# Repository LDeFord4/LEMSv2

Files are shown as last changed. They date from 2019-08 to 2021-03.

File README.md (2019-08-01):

# LEMSv2
This is the repository for the second version of the LEMS Sensor Stations. Stay tuned, information will be added as it is generated. A majority of the documentation will be added to this file.

Note that a peer-reviewed description of LEMSv1 may be found here: https://iopscience.iop.org/article/10.1088/1361-6501/aa97fb

### General TODO

1. Check validity of filenames with more than 8 characters
2. Decagon, the manufacturer of the 5TM soil sensors, has changed their name to Meter, and the 5TM is now called the ECH20 5TM. The DS2 is now called the Atmos 22. The documentation will need to be changed and will probably be done slowly.
3. Major Change: Change the code to read parameters from a text file on the SD card. See if possible to read code from SD card.
4. Delete or separate "File List" from README? Makes it clunky, hard to keep updated. Goal is for files to self explanatory 
5. Update DS2 code to use EnviroDIY's SDI12 library instead of custom library

### PCB TODO
1. Change the parts in the eagle files for BOM lines 11, 29, 30. These parts were out of stock and were replaced by different parts during manufacturing.

### File List
* Code/
  * `Code Instructions.md` - Instructions for uploading
  * LEMSv2/
    * `LEMSv2.ino` - LEMS Arduino Code
    * `DS3231_Alarm1.h` - Header file for corresponding `.cpp` file
    * `DS3231_Alarm1.cpp` - File used to set DS3231 Alarm 1. Developed in test code then copied to this folder
    * `d5TM.h` - Header file for corresponding `.cpp` file
    * `d5TM.cpp` - Library used to interact with 5TM. Developed in test code then copied to this folder
  * Test Code/
    * ADS1115_Test/
      * `ADS1115_Test.ino` - Test code for ADS1115 ADC
    * DS3231_Test/
      * `DS3231_Test.ino` - Test code for DS3231 RTC. Test DS3231 alarm 1
      * `DS3231_Alarm1.h` - Header file for corresponding `.cpp` file
      * `DS3231_Alarm1.c` - Library used to set DS3231 Alarm 1. Developed in here then copied to main code folder
    * DS2_Test/
      * `DS2_Test.ino` - Test code for DS2 anemometer
      * `DS2.h` - Header file for corresponding `.cpp` file
      * `DS2.cpp` - Library used to interact with DS2. Developed here then copied to main code folder
      * `LICENSE` - License to be included with the `SDI12_Zero` library
      * `LICENSE-examples.md` - License to be included with the `SDI12_Zero` library
      * `SDI12_Zero.h` - Header file for corresponding `.cpp` file
      * `SDI12_Zero.cpp` - Library used by DS2 library to interact with DS2. Implements the SDI12 protocal for Arduino Zero.
    * Li200_Test/
      * `Li200_Test.ino` - Test Li200 with intermediate values in calculations printed
    * Teros21_Test/
      * `Teros21_Test.ino` - Test Teros21 and library.
    * Test_5TM/
      * `Test_5TM.ino` - Test code for 5TM Library. 5TM has been working since LEMSv1 but is now made into a library.
      * `d5TM.h` - Header file for corresponding `.cpp` file
      * `d5TM.cpp` - Library used to interact with 5TM. Developed here then copied to main code folder
  * Time_Set/
    * `Time_Set.ino` - Code used to set the time on the DS3231 real time clock
* Data Manipulation/
  * `LemsPlot.m` - View LEMSv2 data plots. Not perfectly adaptable to any file, but will work for a fully instrumented station. To work properly, requires the [Intelligent Dynamic Date Ticks](https://www.mathworks.com/matlabcentral/fileexchange/27075-intelligent-dynamic-date-ticks) file from MathWorks. Can work without it though by commenting out the lines that use it.
  * `importfile.m` - Used to import the LEMSv2 data files. Can only be used on data files from fully instrumented LEMS.
* Hardware Information/
  * `Bill of Materials.xlsx` - Complete parts list
  * `Calibration Constants.xlsx` - Calibration constants for various instruments. For now, only contains Li200 constants.
  * Data Sheets/
    * Multiple data sheets for components
  * Li200R Base/
    * Solidworks/
      * Contains Solidworks files for Li200R base
    * STL Files/
      * Contains print ready STL files for Li200R base
    * `Build Instructions.md` - Tools required for making the Li200R base
  * MLX Housing/
    * `MLX Housing Build Instructions` - Build instructions for MLX90615 housing
  * PCB/
    * `LEMSv2 Board.pdf` - PDF of PCB for easy reference
    * `LEMSv2 Schematic.pdf` - PDF of schematic for easy reference
    * `SAMD21 Breakout Board.jpg` - Reference picture for microcontroller board
  * `Pin List.xlsx` - Pin connection list for SAMD21 Dev Breakout Board
  * `Possible Parts.txt` - Potential parts/Manufacturers to add/use in the future
  * Transimpedance Amplifier/
    * `Transimpedance_Amplifier_Calculations.ipynb` - Jupyter notebook containing transimpedance amplifier calculations
  * `Wiring Information.xlsx` - Information about wiring. What connects to what, etc. Work in progress.
* `LICENSE.TXT` - License
* PCB/
  * LEMSv2 PCB/
    * `Centroid_ScreamingCircuits_smd.ulp` - Eagle ULP script to create centroid data for screaming circuits
    * Gerbers/
      * Contains gerbers for board, plus the panelized gerbers supplied by OSH Park. Also contains the centroid file for Screaming Circuits.
    * `LEMSv2.sch` - LEMSv2 shield schematic
    * `LEMSv2.brd` - LEMSv2 shield layout
    * `OSH_DesignRules.dru` - Eagle design rules for OSH Park
    * `OSHPark_2layer_Eagle7.2.cam` - Modified cam job for OSH Park
  * LEMSv2 PCB Library/
    * `LEMSv2.lbr` - Parts used in the LEMSv2 shield
* `Possible Problems.md` - List of potential hardware problems in the LEMS. Prefer to not have duplicate entries, i.e. one line per problem.
* `README.md` - If you read this line you're actually reading the README. Good job!

### Dependencies
Only 3rd party software dependencies are included in this list. Libraries built into the Arduino software or created for the LEMSv2 software isn't included. You will need the most recent version of the [Arduino IDE](https://www.arduino.cc/en/Main/Software) installed.

* [Adafruit RTC Library](https://github.com/adafruit/RTClib)
* [Adafruit SHT31 Library](https://github.com/adafruit/Adafruit_SHT31)
* [Adafruit Sensor Library](https://github.com/adafruit/Adafruit_Sensor)
* [Adafruit BMP280 Library](https://github.com/adafruit/Adafruit_BMP280_Library)
* [Adafruit MLX90614 Library](https://github.com/adafruit/Adafruit-MLX90614-Library)
* [EnviroDIY SDI-12 Library](https://github.com/EnviroDIY/Arduino-SDI-12) 
* [Soligen2010's fork of the Adafruit ADS1x15 Library](https://github.com/soligen2010/Adafruit_ADS1X15). The default Adafruit ADS1x15 library **doesn't** work.
* In addition, the Sparkfun SAMD21 [board definition](https://raw.githubusercontent.com/sparkfun/Arduino_Boards/master/IDE_Board_Manager/package_sparkfun_index.json
  ) needs to be installed into the Arduino IDE. See [here](https://learn.sparkfun.com/tutorials/samd21-minidev-breakout-hookup-guide/setting-up-arduino) for more info.

### Miscellaneous Notes

- ADS1115 single ended resolution calculation information can be found [here](https://e2e.ti.com/support/data_converters/precision_data_converters/f/73/t/489070)
- ADS1115 over range input information can be found [here](https://e2e.ti.com/support/data_converters/precision_data_converters/f/73/p/398187/1407689#1407689) and [here](https://e2e.ti.com/support/data_converters/precision_data_converters/f/73/t/378122)

### Acknowledgements

* Thanks to [Sparkfun](https://www.sparkfun.com) and [Adafruit](https://www.adafruit.com) for Arduino libraries, components, tutorials, and eagle parts. Many designs and eagle components are directly used from them. Also thanks to [OSH Park](www.oshpark.com) and [Screaming Circuits](www.screamingcircuits.com) for the excellent PCBs and assembly. They were instrumental in getting LEMSv2 completed.

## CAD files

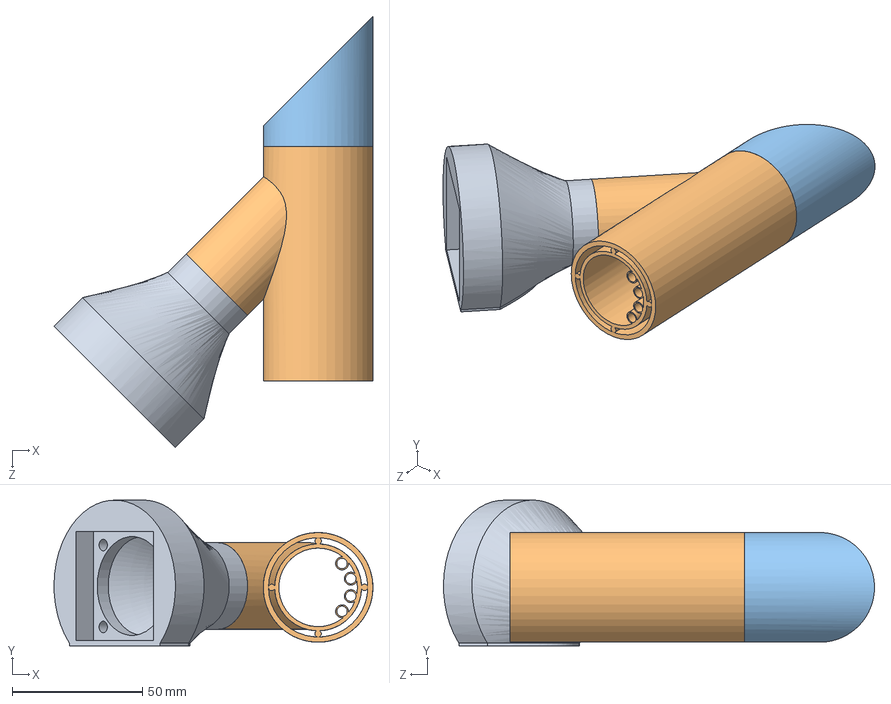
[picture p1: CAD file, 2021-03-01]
Original V2 part files/Assem Short Length C Flat Half 1.SLDASM
122.6 x 56.0 x 165.6 mm
Fan Bell C Flat
Sensor Unit Straws Angled Condensed
Double-Walled Pipe 0.05m with Dowels

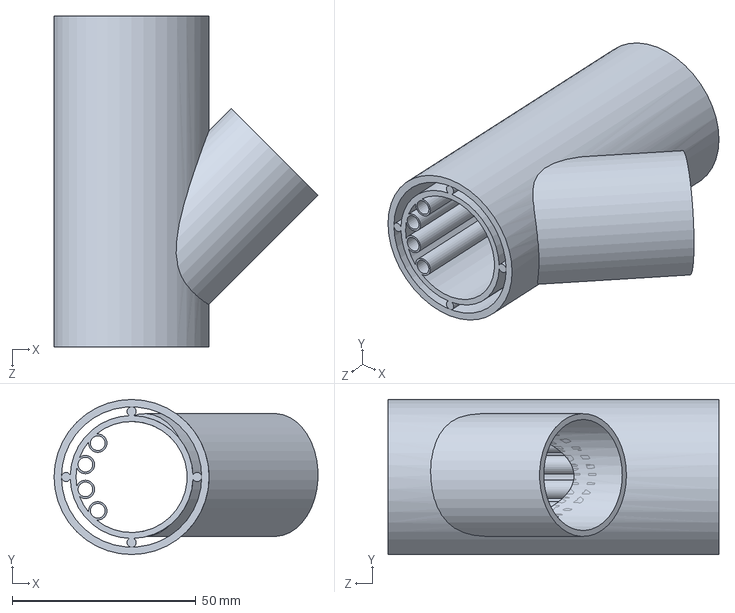
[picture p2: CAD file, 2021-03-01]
Original V2 part files/Sensor Unit Straws Angled Condensed.SLDPRT
71.8 x 42.2 x 90.0 mm

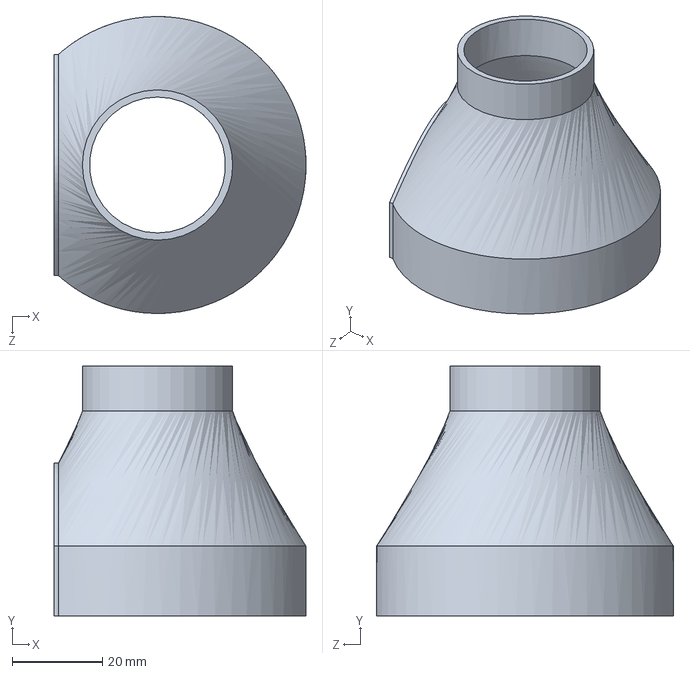
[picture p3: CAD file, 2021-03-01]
Original V2 part files/Fan Bell C Flat.SLDPRT
56.0 x 55.5 x 66.0 mm

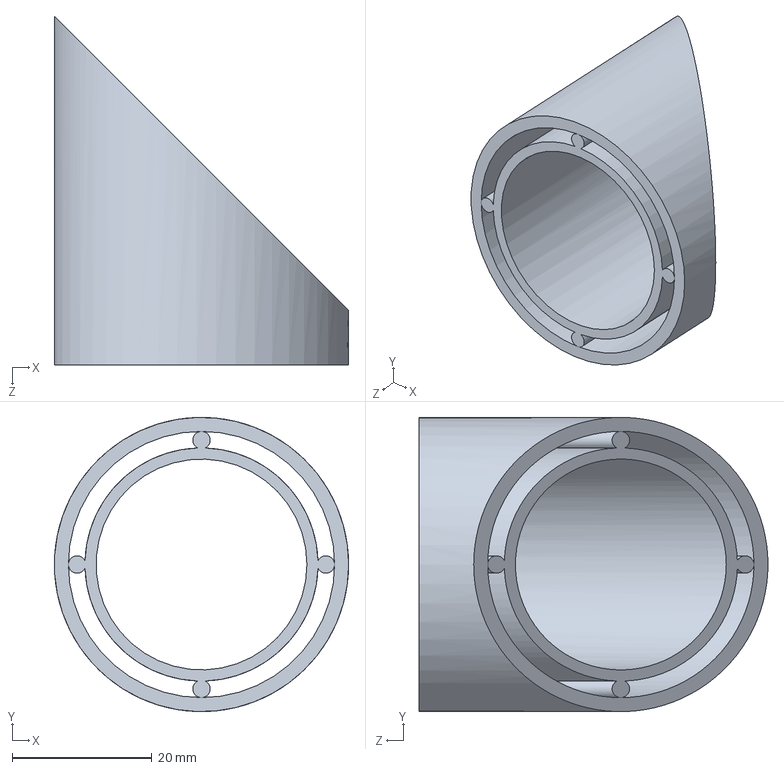
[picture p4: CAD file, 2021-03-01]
Original V2 part files/Double-Walled Pipe 0.05m with Dowels.SLDPRT
42.2 x 42.1 x 50.0 mm

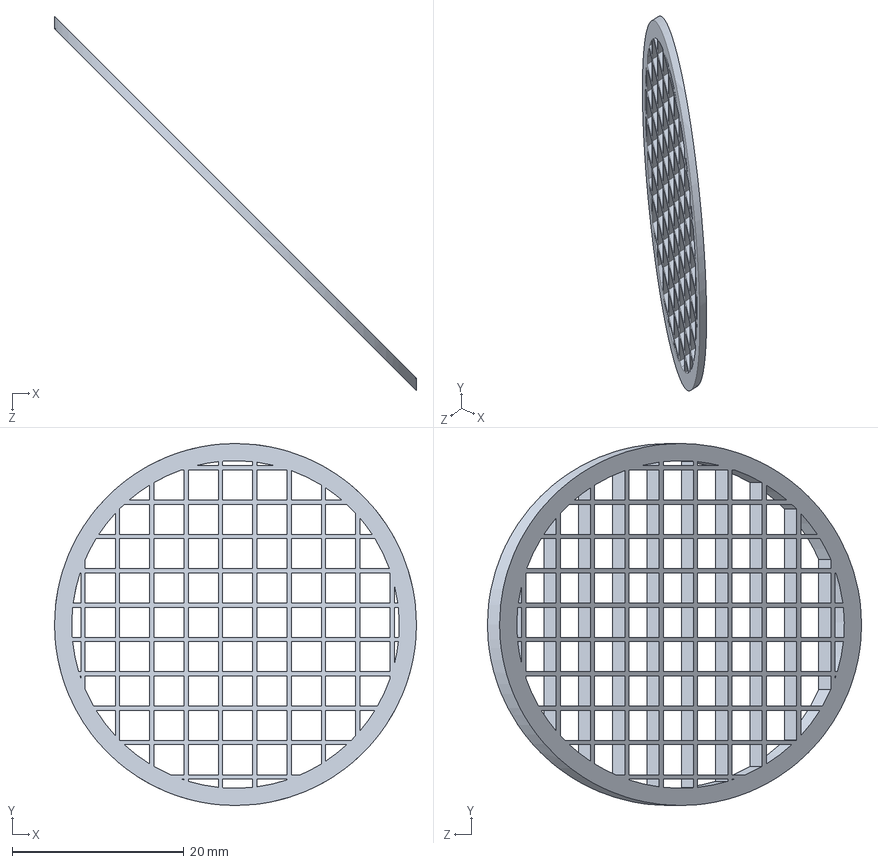
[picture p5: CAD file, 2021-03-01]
Original V2 part files/Net for Pipe Terminus Slanted.SLDPRT
42.2 x 42.2 x 43.6 mm

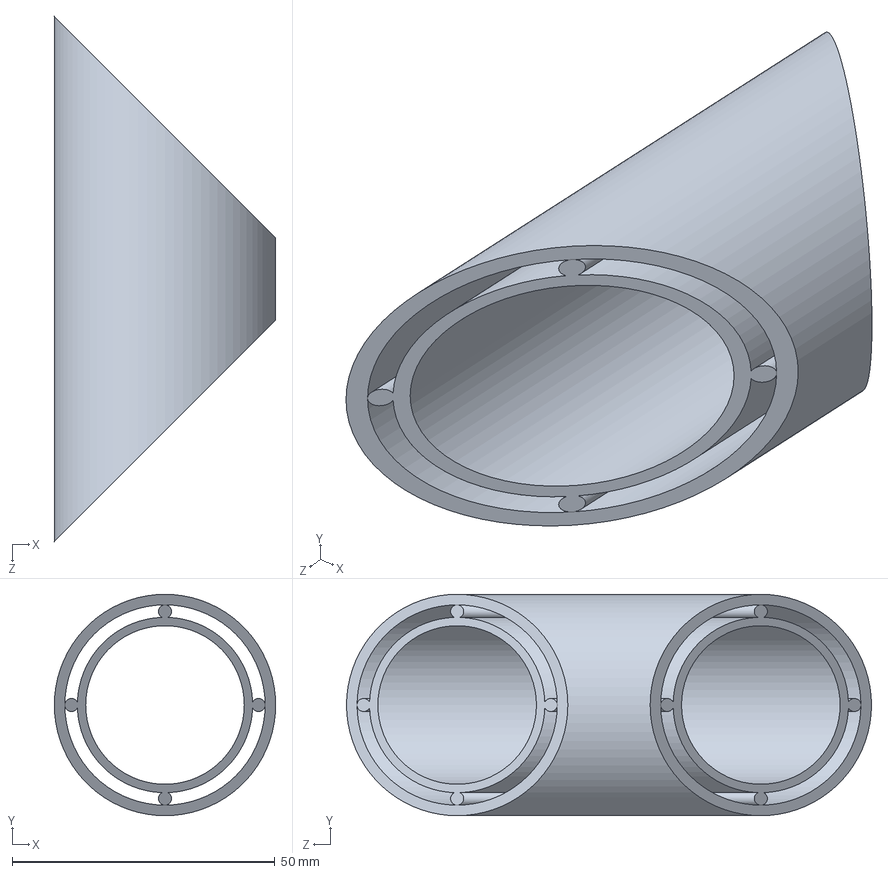
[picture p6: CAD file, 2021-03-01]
Original V2 part files/DoubleWallBeakedPipe100mm.SLDPRT
42.2 x 42.2 x 100.0 mm

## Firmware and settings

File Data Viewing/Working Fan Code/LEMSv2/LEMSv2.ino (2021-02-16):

// ------------------------------------------------------------------------------------------------
// Filename:
//		LEMSv2.ino
//
// Author:
//		Nipun Gunawardena
//
// Description:
//		LEMSv2 Arduino Code
//
// Credits:
//		Thanks to all the 3rd party libraries, especially to Adafruit for the excellent
//		libraries and hardware. More specifics to be added as needed
//    - Sleep code taken from https://github.com/rocketscream/Low-Power/blob/master/LowPower.cpp
//      Thanks to @sandeepmistry at https://github.com/arduino/ArduinoCore-samd/issues/142 for further help
//
// Requirements:
//		- LEMS Hardware
//		- Libraries in libraries list
//
// Notes:
//		- As far as I know, extra files have to be in the same folder as the sketch. Therefore,
//      the DS3231 alarm files have to be copied from their test folder. This means there are
//      possibilities for code divergence. Be aware.
//
// Todo:
//    - Fix battery and Licor Resistors
//
// ------------------------------------------------------------------------------------------------



// Sensor Defines: Plugged in sensors should be defined as 1 --------------------------------------
// TODO: Depreciate Wind
#define TEMPRH 1
#define IR 0
#define UPPERSOIL 0
#define LOWERSOIL 0
#define SUNLIGHT 1
#define PRESSURE 0
#define SONIC 1
#define WIND 1
#define PYRGEOMETER 0
#define FAN 1

// Time Defines, for turning on/off the fan -------------------------------------------------------
//NB: if the LEMS is in UTC time, must enter the fanOn and fanOff in UTC time too
const double fanOn = 3;  //hour of the morning to turn fan on
const double fanOff = 20; //hour of night to turn fan off


// Other Defines ----------------------------------------------------------------------------------
// !! ALERT !! When DEBUG is defined as 0, the LEMSv2 will only work properly under battery or
// external power, NOT under USB power. If you would like to power the LEMS via USB but have DEBUG
// set to 0, uncomment the three lines centered around the line that has USBDevice.detach(); This
// should be near line 207 in the code.
#define DEBUG 0



// Pin Defines ------------------------------------------------------------------------------------
#define GREEN_LED_PIN 6     // Green LED pin
#define RED_LED_PIN 7       // Red LED pin
#define BLUE_LED_PIN 13     // Built-in Blue LED - Sparkfun SAMD21 Dev Board

#define CARDSELECT 5        // SD  card chip select pin
#define RTC_ALARM_PIN 9     // DS3231 Alarm pin
#define BAT_PIN A5          // Battery resistor div. pin
#define FAN_PIN 4          // Pin for cooling fan (was 11 on original code)

#define WDIR_PIN A4         // Davis wind direction pin
#define WSPD_PIN 8          // Davis wind speed pin

#define USOIL_POW_PIN 2     // 5TM Power Pin, Upper - White 5TM Wire
#define LSOIL_POW_PIN 38    // 5TM Power Pin, Lower - White 5TM Wire
#define USOIL_SER Serial1   // 5TM Serial Port, Upper RX = D0, TX = D1; Red 5TM Wire
#define LSOIL_SER Serial    // 5TM Serial Port, Lower RX = D31, TX = D30; Red 5TM Wire

#define SONIC_PIN 10        // DS2 Data Pin, Red DS2 Wire

#define ADC_RES 12          // Number of bits Arduino ADC has
#define ADS_LI200_PIN 0     // LiCor Li200 pin on ADS1115
#define ADS_VCC_PIN 1       // VCC pin on ADS1115

#define THERM_PIN A3        // SL-610 Thermistor output
#define THERM_POW 3         // Thermistor power pin
// Positive thermopile pin is in AIN2, negative in AIN3.
// Serial Number: SL-610-SS_1034 !! USES NEW WIRING COLORS !!
// OR
// Serial Number: SL-510-SS_1076 !! USES NEW WIRING COLORS !!






// Libraries --------------------------------------------------------------------------------------
#include <SD.h>			            // SD Card Library
#include <SPI.h>		            // SPI Library
#include "DS2.h"                // DS2 Library
#include "d5TM.h"               // 5TM Library
#include <math.h>               // Math Library - https://www.arduino.cc/en/Math/H
#include <Wire.h>		            // I2C Library
#include <RTClib.h>		          // RTC Library - https://github.com/adafruit/RTClib
#include "DS3231_Alarm1.h"      // RTC Alarm Library Files
#include <Adafruit_SHT31.h>     // SHT31 - https://github.com/adafruit/Adafruit_SHT31
#include <Adafruit_Sensor.h>    // Necessary for BMP280 Code - https://github.com/adafruit/Adafruit_Sensor
#include <Adafruit_BMP280.h>    // BMP280 - https://github.com/adafruit/Adafruit_BMP280_Library
#include <Adafruit_ADS1015.h>   // ADS1115 - https://github.com/soligen2010/Adafruit_ADS1X15
#include <Adafruit_MLX90614.h>  // MLX90614 Library - https://github.com/adafruit/Adafruit-MLX90614-Library



// Initialize Variables----------------------------------------------------------------------------

// Real Time Clock
RTC_DS3231 rtc;                 // Real Time Clock Class
DS3231_Alarm1 rtcAlarm1;        // RTC Alarm
volatile bool rtcFlag = false;  // Used for ISR to know when to take measurements
const uint8_t deltaT = 10;      // Sampling time - Seconds

// SD Card
File logfile;                       // File object
char filename[] = "LEMST_00.CSV";   // Initial filename - Whatever this is named, the filename should be 8 characters long and the last two should be digits!

// ADS1115
Adafruit_ADS1115 ads;
double vcc;                         // Actual value of 3.3V supply voltage

// Battery Level - Max output of 14.6V outputs 3.2444V on A5
double vBat;
const unsigned long R1 = 56000;         // Battery Side Resistor - See https://en.wikipedia.org/wiki/Voltage_divider
const unsigned long R2 = 16000;         // Ground Side Resistor

// MLX90614
#if IR
double mlxIR;                                   // IR values from MLX90614
double mlxAmb;                                  // Ambient temp values from MLX90614
Adafruit_MLX90614 mlx = Adafruit_MLX90614();    // MLX90614 class
#endif

// Upper soil
#if UPPERSOIL
d5TM upperSoil(USOIL_SER, 1200, USOIL_POW_PIN); // Initialize 5TM class
#endif

// Lower soil
#if LOWERSOIL
d5TM lowerSoil(LSOIL_SER, 1200, LSOIL_POW_PIN); // Initialize 5TM class
#endif

// BMP280
#if PRESSURE
Adafruit_BMP280 bmp;         // Initialize BMP280 class
double pressure;             // Barometric pressure
double bmpAmb;               // Temperature from BMP280
double approxAlt;            // Approximate altitude from BMP280
#endif

// Wind
#if WIND
unsigned long startTime;            // Used to measure averaging period for wind speed
volatile unsigned long windCount;   // Counts to convert to speed
double wDir;                         // Wind direction
double wSpd;                         // Wind speed
#endif

#if SUNLIGHT
double rawSun = 0;                       // Float to hold voltage read from ADS1115
const double liConst = 5.258E-8;  // Licor Calibration Constant. Units of (Amps/(W/m^2))
const double ampResistor = 64900;        // Exact Resistor Value used by Op-Amp in Ohms
double sunlight = 0.0;                   // Converted Value
#endif

// SHT21
#if TEMPRH
Adafruit_SHT31 sht = Adafruit_SHT31();
double shtAmb;               // Ambient temp values from SHT21
double shtHum;               // Relative humidity values from SHT21
#endif

//Fan for SHT
#if FAN
bool fanSwitch = true;        // if true, fan is on, if false, fan is off
#endif

// DS2
#if SONIC
DS2 sonic(SONIC_PIN, '0');   // Initialize DS2 class
double sonicDir;             // Wind direction from sonic
double sonicSpd;             // Wind speed from sonic
double sonicGst;             // Wind gust from sonic
double sonicTmp;             // Wind temperature from sonic
#endif

// Pyrgeometer
#if PYRGEOMETER

// Thermistor variables
double thermV;            // Voltage reading from arduino ADC for thermistor (volts)
double Rt;                // Thermistor resistance (ohm)
double thermTemp;         // Temperature as measured by thermistor (Kelvin)
double Agz = 9.32793534266128e-4;  // Greater than 0 C thermistor constants
double Bgz = 2.21450736014070e-4;  // "
double Cgz = 1.26232582309837e-7;  // "
double Alz = 9.32959957496852e-4;  // Less than 0 C thermistor constants
double Blz = 2.21423593265217e-4;  // "
double Clz = 1.26328669787011e-7;  // "
unsigned int rawTemp = 0;          // Analog read from thermistor

// Thermopile Constants & variables
double k1 = 9.712;     // Wm^-2 per mV - Serial number 1034
double k2 = 1.028;     // Unitless - Serial number 1034
//double k1 = 9.786;      // Serial number 1076
//double k2 = 1.031;       // "
double pilemV;         // Voltage from thermopile
double LWi;            // Incoming longwave radiation
#endif






// Setup ------------------------------------------------------------------------------------------
// ************************************************************************************************
void setup() {

#if DEBUG
  while (!SerialUSB);
  SerialUSB.begin(9600);
  SerialUSB.println("Starting Sketch");
#endif
  delay(3000);                                  // Allows to unplug before main code starts

  // Set pins
  pinMode(GREEN_LED_PIN, OUTPUT);
  pinMode(RED_LED_PIN, OUTPUT);
  pinMode(CARDSELECT, OUTPUT);
  analogReadResolution(ADC_RES);                // Set arduino resolution to 12 bit - only works on ARM arduino boards


  // Set fan low in case it's plugged in but not wanting to be used
  // turn fan on for a few seconds to make sure it's working
  pinMode(FAN_PIN, OUTPUT);
  
#if FAN
  digitalWrite(FAN_PIN, HIGH);
  delay(2000);
  digitalWrite(FAN_PIN, LOW);
#endif


  // Turn on LED during setup process
  digitalWrite(GREEN_LED_PIN, HIGH);

  // ADS1115 begin
  ads.setGain(GAIN_ONE);        // 1x gain   +/- 4.096V  1 bit = 0.000125V
  ads.begin();

  // Setup registers so interrupts wake board from sleep
  SYSCTRL->VREG.bit.RUNSTDBY = 1;              // Configure regulator to run normally in standby mode, so not limited to 50uA
  SYSCTRL->DFLLCTRL.bit.RUNSTDBY = 1;          // Enable DFLL48MHz clock in standby mode

  // Disable USB device to avoid USB interrupts. Necessitates double press of reset button to upload though
  // This is only needed when DEBUG is 0, AND you want to power the LEMSv2 from USB power for some reason
  //  #if !DEBUG
  //    USBDevice.detach();
  //  #endif

  // RTC Setup
  if (!rtc.begin()) {
    error("Couldn't Find RTC!");
  }

  // Attach Interrupt - Interrupts from RTC used instead of delay()
  attachInterrupt(RTC_ALARM_PIN, rtcISR, FALLING);

  // Check for Card Present
  if (!SD.begin(CARDSELECT)) {
    error("Card Init. Failed!");
  }

  // Check for new filename
  for (uint8_t i = 0; i < 100; i++) {
    filename[6] = '0' + i / 10;
    filename[7] = '0' + i % 10;
    if (! SD.exists(filename)) {
      break;
    }
  }

  // Open file
  logfile = SD.open(filename, FILE_WRITE);
  if (!logfile) {
    error("Couldn't Create File!");
  }
#if DEBUG
  SerialUSB.print("Writing to ");
  SerialUSB.println(filename);
#endif

  // Write Header - Debug header at end of setup()
  // Sensors also initiated here
  logfile.print("Year,Month,Date,Hour,Minute,Second,Bat_Lvl");
#if IR
  mlx.begin();
  logfile.print(",MLX_IR_C,MLX_Amb_C");
#endif
#if UPPERSOIL
  upperSoil.begin();
  logfile.print(",Upper_Soil_Temp,Upper_Soil_Mois");
#endif
#if LOWERSOIL
  lowerSoil.begin();
  logfile.print(",Lower_Soil_Temp,Lower_Soil_Mois");
#endif
#if PRESSURE
  bmp.begin();
  logfile.print(",Pressure,BMP_Amb");
#endif
#if WIND
  logfile.print(",Wind_Dir,Wind_Spd");
  pinMode(WSPD_PIN, INPUT_PULLUP);
#endif
#if SONIC
  logfile.print(",Sonic_Dir,Sonic_Spd,Sonic_Gst,Sonic_Tmp");
  sonic.begin();
#endif
#if SUNLIGHT
  logfile.print(",Sunlight");
#endif
#if PYRGEOMETER
  pinMode(THERM_POW, OUTPUT);
  digitalWrite(THERM_POW, LOW);
  logfile.print(",Longwave,Thermistor_Tmp,Pile_mV,thermV");
#endif
#if TEMPRH
  sht.begin(0x44);    // Set to 0x45 for alt. i2c address
  logfile.print(",SHT_Amb_C,SHT_Hum_Pct");
#endif
#if FAN
digitalWrite(FAN_PIN, HIGH); //for testing, turning fan on (continuously)
  logfile.print(",Fan_Switch");
#endif
  logfile.println();

  // Delay and indicate start
  delay(3500);
  digitalWrite(GREEN_LED_PIN, LOW);

  // Wait for next time with evenly divisible deltaT, then set alarm
  // If alarm set time is <1 second away, wait for next even value
  DateTime now = rtc.now();
  uint8_t setSec;                           // Seconds value to set alarm to
  uint8_t rem = now.second() % deltaT;      // Seconds since last set point
  rem = deltaT - rem;                       // Calculate seconds until next set point
  setSec = ((rem == 1) ? 1 + deltaT : rem); // Set to next *convenient* set point
  rtcAlarm1.alarmSecondsSet(now, setSec);
  rtcAlarm1.alarmOn();
  rtcFlag = false;
#if DEBUG
  SerialUSB.print("Setting RTC alarm to ");
  SerialUSB.print(deltaT);
  SerialUSB.println(" second evenly divisible start point");
  SerialUSB.print("Current Seconds: ");
  SerialUSB.print(now.second());
  SerialUSB.print(" || Setting alarm to ");
  SerialUSB.print(setSec);
  SerialUSB.println(" seconds from now. Entering Loop...");
  SerialUSB.println();
#endif

} // End setup()






// Loop -------------------------------------------------------------------------------------------
// ************************************************************************************************
void loop() {
  // Wait for interrupt

  digitalWrite(GREEN_LED_PIN, rtcFlag);    // Turn LED off
#if DEBUG
  while (!rtcFlag);                        // Use while loop to avoid sleep states or debugging
#else
  standbySleep();                          // Use standbySleep() to reduce power consumption
#endif

  // Gather Measurements
  DateTime now = rtc.now();
  vcc = ads.readADC_SingleEnded_V(ADS_VCC_PIN);       // VCC connected to AIN1
  vBat = double(analogRead(BAT_PIN)) * (vcc / pow(2, ADC_RES)) * double(R1 + R2) / double(R2);
#if IR
  mlxIR = mlx.readObjectTempC();
  mlxAmb = mlx.readAmbientTempC();
#endif
#if UPPERSOIL
  upperSoil.getMeasurements();
#endif
#if LOWERSOIL
  lowerSoil.getMeasurements();
#endif
#if PRESSURE
  bmpAmb = bmp.readTemperature();
  pressure = bmp.readPressure();
#endif
#if SUNLIGHT
  rawSun = ads.readADC_SingleEnded_V(ADS_LI200_PIN);                     // LiCor Amplifier connected to AIN0
  sunlight = rawSun * (1.0 / ampResistor) * (1.0 / liConst); // Convert to W/m^2
#endif
#if TEMPRH
  shtAmb = sht.readTemperature();
  shtHum = sht.readHumidity();
#endif
#if FAN
  fanSwitch = true; //every cycle we reset the fanSwitch to true, and only if one of the battery, time, or sunlight
  //switches are tripped does the fanSwtich become false

//  #if SUNLIGHT
//  if (vBat < 12.0 ||(now.hour() < fanOn) || (now.hour() > fanOff) || sunlight < 50) {
//    fanSwitch = false;
//  }
//  #endif
//  
//  if (vBat < 12.0 ||(now.hour() < fanOn) || (now.hour() > fanOff)) {
//    fanSwitch = false;
//  }

if (vBat < 12.0) {
  fanSwitch == false;
}

  if (fanSwitch == true) {
    digitalWrite(FAN_PIN, HIGH);
  }
  else {
    digitalWrite(FAN_PIN, LOW);
  }
#endif
#if SONIC
  sonic.getMeasurements();
#endif
#if PYRGEOMETER
  ads.setGain(GAIN_SIXTEEN);

  // Read thermistor temperature
  digitalWrite(THERM_POW, HIGH);
  rawTemp = analogRead(THERM_PIN);
  digitalWrite(THERM_POW, LOW);
  thermV = double(rawTemp) / (pow(2, ADC_RES) - 1) * vcc;
  Rt = 24900.0 * thermV / (vcc - thermV);
  if (Rt >= 94980) { // If greater than this value, means temp is less than zero
    thermTemp = 1.0 / (Alz + Blz * log(Rt) + Clz * pow(log(Rt), 3));
  } else {
    thermTemp = 1.0 / (Agz + Bgz * log(Rt) + Cgz * pow(log(Rt), 3));
  }

  // Read thermopile
  pilemV = ads.readADC_Differential_2_3_V() * 1000.0; // Positive thermopile pin is in AIN2, negative in AIN3.
  LWi = k1 * pilemV + k2 * 5.6704e-8 * pow(thermTemp, 4);

  // Convert to Celsius
  thermTemp = thermTemp - 273.15;

  ads.setGain(GAIN_ONE);
#endif
#if WIND
  wDir = (double)analogRead(WDIR_PIN) * 360.0 / pow(2, ADC_RES);  // Map from analog count to 0-360, with 360=North
  startTime = millis();
  attachInterrupt(WSPD_PIN, windCounter, RISING);                 // Attach interrupt for wind speed pin
  while (millis() - startTime < 4500);                            // Measure number of counts in 4.5 sec
  detachInterrupt(WSPD_PIN);
  wSpd = windCount * (2.25 / 4.5);                                // mph = (counts)*(2.25)/(sample period in seconds). If period is 2.25 seconds, mph = counts
  wSpd = 0.447 * wSpd;                                            // Convert to m/s
#endif


  // Log Data
  digitalWrite(GREEN_LED_PIN, rtcFlag);    // Turn LED on
  logfile.print(now.year());
  logfile.print(",");
  logfile.print(now.month());
  logfile.print(",");
  logfile.print(now.day());
  logfile.print(",");
  logfile.print(now.hour());
  logfile.print(",");
  logfile.print(now.minute());
  logfile.print(",");
  logfile.print(now.second());
  logfile.print(",");
  logfile.print(vBat);
#if IR
  logfile.print(",");
  logfile.print(mlxIR);
  logfile.print(",");
  logfile.print(mlxAmb);
#endif
#if UPPERSOIL
  logfile.print(",");
  logfile.print(upperSoil.temperature);
  logfile.print(",");
  logfile.print(upperSoil.moisture);
#endif
#if LOWERSOIL
  logfile.print(",");
  logfile.print(lowerSoil.temperature);
  logfile.print(",");
  logfile.print(lowerSoil.moisture);
#endif
#if PRESSURE
  logfile.print(",");
  logfile.print(pressure);
  logfile.print(",");
  logfile.print(bmpAmb);
#endif
#if WIND
  logfile.print(",");
  logfile.print(wDir);
  logfile.print(",");
  logfile.print(wSpd);
#endif
#if SONIC
  logfile.print(",");
  logfile.print(sonic.wDir);
  logfile.print(",");
  logfile.print(sonic.wSpd);
  logfile.print(",");
  logfile.print(sonic.wGst);
  logfile.print(",");
  logfile.print(sonic.wTmp);
#endif
#if SUNLIGHT
  logfile.print(",");
  logfile.print(sunlight);
#endif
#if PYRGEOMETER
  logfile.print(",");
  logfile.print(LWi);
  logfile.print(",");
  logfile.print(thermTemp);
  logfile.print(",");
  logfile.print(pilemV,6);
  logfile.print(",");
  logfile.print(thermV,6);
#endif
#if TEMPRH
  logfile.print(",");
  logfile.print(shtAmb);
  logfile.print(",");
  logfile.print(shtHum);
#endif
#if FAN
  logfile.print(",");
  logfile.print(fanSwitch);
#endif
  logfile.println();
  logfile.flush();


  // Debug Info
#if DEBUG
  SerialUSB.print(now.year(), DEC);
  SerialUSB.print(", ");
  SerialUSB.print(now.month(), DEC);
  SerialUSB.print(", ");
  SerialUSB.print(now.day(), DEC);
  SerialUSB.print(", ");
  SerialUSB.print(now.hour(), DEC);
  SerialUSB.print(", ");
  SerialUSB.print(now.minute(), DEC);
  SerialUSB.print(", ");
  SerialUSB.print(now.second(), DEC);
  SerialUSB.print(", ");
  SerialUSB.print(vBat);
#if IR
  SerialUSB.print(", ");
  SerialUSB.print(mlxIR);
  SerialUSB.print(", ");
  SerialUSB.print(mlxAmb);
#endif
#if UPPERSOIL
  SerialUSB.print(", ");
  SerialUSB.print(upperSoil.temperature);
  SerialUSB.print(", ");
  SerialUSB.print(upperSoil.moisture);
#endif
#if LOWERSOIL
  SerialUSB.print(", ");
  SerialUSB.print(lowerSoil.temperature);
  SerialUSB.print(", ");
  SerialUSB.print(lowerSoil.moisture);
#endif
#if PRESSURE
  SerialUSB.print(", ");
  SerialUSB.print(pressure);
  SerialUSB.print(", ");
  SerialUSB.print(bmpAmb);
#endif
#if WIND
  SerialUSB.print(", ");
  SerialUSB.print(wDir);
  SerialUSB.print(", ");
  SerialUSB.print(wSpd);
#endif
#if SONIC
  SerialUSB.print(", ");
  SerialUSB.print(sonic.wDir);
  SerialUSB.print(", ");
  SerialUSB.print(sonic.wSpd);
  SerialUSB.print(", ");
  SerialUSB.print(sonic.wGst);
  SerialUSB.print(", ");
  SerialUSB.print(sonic.wTmp);
#endif
#if SUNLIGHT
  SerialUSB.print(", ");
  SerialUSB.print(sunlight);
#endif
#if PYRGEOMETER
  SerialUSB.print(", ");
  SerialUSB.print(LWi);
  SerialUSB.print(", ");
  SerialUSB.print(thermTemp);
#endif
#if TEMPRH
  SerialUSB.print(", ");
  SerialUSB.print(shtAmb);
  SerialUSB.print(", ");
  SerialUSB.print(shtHum);
#endif
#if FAN
  SerialUSB.print(", ");
  SerialUSB.print(fanSwitch);
#endif
  SerialUSB.println();
#endif

  // Delay just a little bit for longer blink
  delay(50);

  // Reset any variables and turn alarm on for next measurement
#if WIND
  windCount = 0;
#endif
  rtcAlarm1.alarmSecondsSet(now, deltaT);
  rtcFlag = false;


} // End loop()






// Functions --------------------------------------------------------------------------------------
// ************************************************************************************************

// Turn red LED on and loop. Used in case of errors
void error(String errorMsg) {
#if DEBUG
  SerialUSB.println(errorMsg);
#endif
  digitalWrite(GREEN_LED_PIN, LOW);   // Ensure green LED is off
  while (true) {
    digitalWrite(RED_LED_PIN, HIGH);
    delay(300);
    digitalWrite(RED_LED_PIN, LOW);
    delay(3000);
  }
}


// ISR for RTC alarm. Used to break out of while loop used instead of delay
void rtcISR(void) {
  rtcFlag = true;
}


// ISR for Davis Anemometer. Increments wind counter with every revolution
#if WIND
void windCounter() {
  windCount++;
}
#endif


// Function to put SAMD21 into standby sleep
void standbySleep(void) {
  SCB->SCR |= SCB_SCR_SLEEPDEEP_Msk;
  __WFI();
}

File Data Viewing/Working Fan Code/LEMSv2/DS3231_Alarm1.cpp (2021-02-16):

// ------------------------------------------------------------------------------------------------
// Filename:
//    DS3231_Alarm1.cpp
//
// Author:
//    Nipun Gunawardena
//
// Description:
//    Simple library to set and manipulate alarm1 on DS3231
//
// Credits:
//    Thanks to Adafruit's RTClib. Many components of this library are heavily borrowed from that
//    one
//
// Requirements:
//    - DS3231 Hardware
//    - DS3231_Alarm.h
//
// Notes:
//    None for now
//
// Todo:
//    -
//
// ------------------------------------------------------------------------------------------------






// Includes and Defines - Boilerplate from Adafruit Libraries -------------------------------------
#include <Wire.h>
#include "DS3231_Alarm1.h"
#ifdef __AVR__
#include <avr/pgmspace.h>
#elif defined(ESP8266)
#include <pgmspace.h>
#elif defined(ARDUINO_ARCH_SAMD)
// nothing special needed
#elif defined(ARDUINO_SAM_DUE)
#define PROGMEM
#define pgm_read_byte(addr) (*(const unsigned char *)(addr))
#define Wire Wire1
#endif

#if (ARDUINO >= 100)
#include <Arduino.h> // capital A so it is error prone on case-sensitive filesystems
// Macro to deal with the difference in I2C write functions from old and new Arduino versions.
#define _I2C_WRITE write
#define _I2C_READ  read
#else
#include <WProgram.h>
#define _I2C_WRITE send
#define _I2C_READ  receive
#endif






// Functions --------------------------------------------------------------------------------------
// read/write_i2c_register taken from adafruit libraries
static uint8_t read_i2c_register(uint8_t addr, uint8_t reg) {
  Wire.beginTransmission(addr);
  Wire._I2C_WRITE((byte)reg);
  Wire.endTransmission();

  Wire.requestFrom(addr, (byte)1);
  return Wire._I2C_READ();
}

static void write_i2c_register(uint8_t addr, uint8_t reg, uint8_t val) {
  Wire.beginTransmission(addr);
  Wire._I2C_WRITE((byte)reg);
  Wire._I2C_WRITE((byte)val);
  Wire.endTransmission();
}

// Also taken from adafruit libraries
static uint8_t bcd2bin (uint8_t val) { return val - 6 * (val >> 4); }
static uint8_t bin2bcd (uint8_t val) { return val + 6 * (val / 10); }






// Class Functions --------------------------------------------------------------------------------
DS3231_Alarm1::DS3231_Alarm1(void) {
  // Class constructor. As of now, does nothing
}


void DS3231_Alarm1::alarmOn(void) {
  // Clear Alarm1 bits
  uint8_t statReg = read_i2c_register(DS3231_ADDRESS, DS3231_REG_STATUS_CTL);
  statReg &= ~B00000001;      // Set A1F off
  write_i2c_register(DS3231_ADDRESS, DS3231_REG_STATUS_CTL, statReg);

  // Turn DS3231 Alarm1 On
  uint8_t ctrlReg = read_i2c_register(DS3231_ADDRESS, DS3231_REG_CONTROL);
  ctrlReg |= B00000101;      // Set INTCN and A1IE on
  write_i2c_register(DS3231_ADDRESS, DS3231_REG_CONTROL, ctrlReg);
}


void DS3231_Alarm1::alarmOff(void) {
  // Clear Alarm1 bits
  uint8_t statReg = read_i2c_register(DS3231_ADDRESS, DS3231_REG_STATUS_CTL);
  statReg &= ~B00000001;      // Set A1F off
  write_i2c_register(DS3231_ADDRESS, DS3231_REG_STATUS_CTL, statReg);

  // Turn DS3231 Alarm1 Off
  uint8_t ctrlReg = read_i2c_register(DS3231_ADDRESS, DS3231_REG_CONTROL);
  ctrlReg &= ~B00000001;      // Set A1IE off
  write_i2c_register(DS3231_ADDRESS, DS3231_REG_CONTROL, ctrlReg);
}


void DS3231_Alarm1::alarmSecondsSet(DateTime currentTime, int32_t delSeconds) {
  // Set alarm 1 to match seconds only
  DateTime setTime(currentTime + TimeSpan(delSeconds));
  uint8_t setSeconds = bin2bcd(setTime.second());

  // Send seconds data
  Wire.beginTransmission(DS3231_ADDRESS);
  Wire._I2C_WRITE((byte)DS3231_REG_A1SECONDS);
  Wire._I2C_WRITE((byte)(setSeconds & 0x7F));   // Send seconds
  Wire._I2C_WRITE((byte)0x80);                  // Send masks so alarm rings on seconds
  Wire._I2C_WRITE((byte)0x80);
  Wire._I2C_WRITE((byte)0x80);
  Wire.endTransmission();

  // Clear Alarm1 bits
  uint8_t statReg = read_i2c_register(DS3231_ADDRESS, DS3231_REG_STATUS_CTL);
  statReg &= ~B00000001;      // Set A1F off
  write_i2c_register(DS3231_ADDRESS, DS3231_REG_STATUS_CTL, statReg);
}

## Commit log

2021-02-02 fan code with series of if statements
    verifiable, but switches don't communicate and so are ineffective
2021-02-02 fanSwitches layered if statements
    battery as most important switch... actually need or statements to fix this
    [LEMSv2.ino]
2021-02-02 Or statements for fanSwitch
    Now, this should work. The if - or statement checks to see if any of the off conditions are met. If they are, fanSwitch becomes false. fanSwitch is returned to true every cycle, and only if a switch 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
2021-02-16 working fan code, python plotting
2021-03-01 Original V2 part files from Sp2020
    [Assem Short Length C Flat Half 1.SLDASM, Double-Walled Pipe 0.05m with Dowels.SLDPRT, DoubleWallBeakedPipe100mm.SLDPRT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]
